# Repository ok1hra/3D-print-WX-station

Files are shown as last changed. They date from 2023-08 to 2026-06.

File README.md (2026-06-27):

# 3D print WX station

Firmware and 3d models

[Wiki page](https://remoteqth.com/w/doku.php?id=3d_print_wx_station)

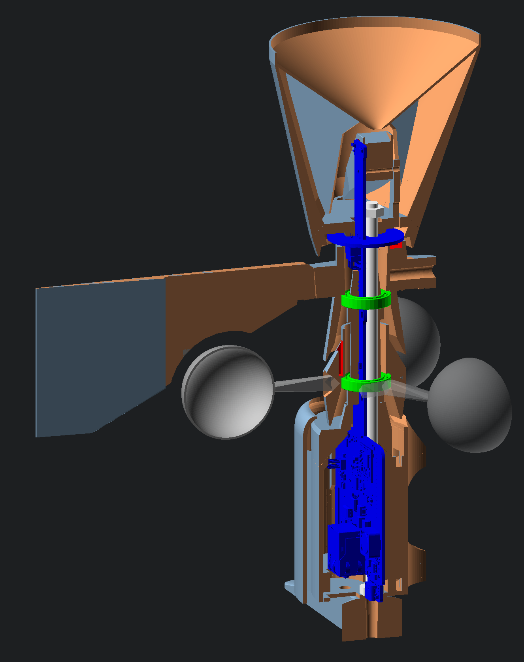
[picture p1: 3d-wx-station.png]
Hardware


## Documentation

- **[Web upload firmware](https://ok1hra.github.io/3D-print-WX-station/)**
- **[Firmware Manual](MANUAL.md)** — network services & ports, web interface,
  serial/telnet console, configuration, building/flashing, and a reference table
  of how often each value is published to MQTT, APRS, windy.com and the dashboard.
- [windy.com setup](WINDY.md) — registering and configuring the windy.com PWS upload.
- [TMEP.cz upload](TMEP.md) — pushing measured values to TMEP.cz (Network tab, per-sensor parameter mapping, NVS config).

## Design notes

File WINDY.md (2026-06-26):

# Sending data to windy.com (PWS)

The WX station can send its measured data to [windy.com](https://www.windy.com)
as a Personal Weather Station (PWS). Communication uses HTTPS to
`stations.windy.com` in a Wunderground-compatible format.

> The feature is enabled in firmware via `#define WINDY` (file `wx.ino`).
> Without an **API key** nothing is sent — uploading is therefore **off by
> default** until you enter the key.

---

## 1. Get an API key

1. Sign in / register at <https://stations.windy.com>.
2. Under **My stations**, *Add a station*:
   - fill in the name, location (lat/lon), altitude and type.
3. After saving, windy generates an **API key** (a long string, up to 123
   characters) and a **Station ID** for the station.
4. Copy the **API key** — you will enter it into the station.

---

## 2. Set the key in the WX station

The key is entered through the configuration menu (telnet or serial console),
just like the other parameters (callsign, coordinates, altitude…).

1. Connect to the station:
   - **telnet** to the station IP (port 23), or
   - **USB serial console** (115200 Bd).
2. Press `?` to list the menu. You will see a new item:

   ```
   K  windy.com API key [empty, upload OFF]
   ```

3. Press `K`.
4. Paste the API key from windy and confirm with **Enter** (`;` on the serial
   console).
5. The station replies, for example:

   ```
   windy API key saved (96 chars)
   ```

   and the menu item changes to `K  windy.com API key [SET, upload ON]`.

The key is stored in EEPROM (addresses 244–367), so it **survives a restart** and
a power loss.

### Disabling uploads / erasing the key
Press `K` and confirm an **empty** input (just Enter). The key is erased and
uploading is turned off:

```
windy upload disabled (key erased)
```

---

## 2b. Public Station ID and the link on the main page

To make a **WINDY** link appear on the station's main web page (port 80) next to
the **APRS** link, also enter the station's public **Station ID**.

- **API key** (step 2) = the secret key used for uploading (~96 characters).
- **Station ID** = the short public identifier in the station's URL, e.g.
  `pws-f06ea43a` (found at <https://stations.windy.com> for the station, i.e. in
  the public URL `https://www.windy.com/station/pws-…`).

To set it:

1. In the menu press `I`.
2. Paste the Station ID (e.g. `pws-f06ea43a`) and confirm with **Enter** (`;` on
   the serial console).
3. The station replies:

   ```
   windy Station ID saved | https://www.windy.com/station/pws-f06ea43a
   ```

The **WINDY** link is shown on the main page **only when both**:
- an API key is set (upload is active), and
- a Station ID is filled in.

Result in the page header:

```
… | APRS | WINDY | Upload FW | …
```

Erase the Station ID by entering an empty value for command `I` (the link then
hides).

---

## 3. Altitude and coordinates

For the data to make sense:

- Set the **altitude** in the menu with command `m` (also used to convert pressure
  to sea level).
- The station coordinates are entered directly on the windy.com website for that
  station.

---

## 4. How often it is sent

Data is sent at the same interval as the other outputs (MQTT, APRS) — the
**"TX repeat time"** in the menu (command `x`), default **5 minutes**.
Windy recommends sending no more often than about once every 5 minutes, so the
default value does not need changing.

---

## 5. What is sent (and in which units)

The firmware converts its internal metric values to the imperial units windy
expects:

| Quantity | windy parameter | unit | firmware conversion |
|---|---|---|---|
| Wind direction | `winddir` | ° | – |
| Wind speed | `windspeedmph`  | mph | m/s ÷ 0.44704 |
| Wind gust | `windgustmph` | mph | m/s ÷ 0.44704 |
| Temperature | `tempf` | °F | °C × 1.8 + 32 |
| Rain (today) | `rainin` | inches  | mm ÷ 25.4 |
| Pressure | `baromin` | inHg | hPa × 0.02953 |
| Dew point | `dewptf` | °F | °C × 1.8 + 32 |
| Humidity | `humidity` | % | – |

---

## 6. Verification / debugging

Enable debugging from the menu with command `*` (debug). The console then shows:

```
[windy] connecting to stations.windy.com ...
[windy] free heap before: 224740
[windy] connected!
[windy] GET /pws/update/XXXX?winddir=...&windspeedmph=... HTTP/1.1
[windy] headers received
[windy RX] ... server response ...
[windy] stop
```

- `connection failed!` → check internet/DNS, the clock (TLS needs a valid time via
  NTP), and that the station has connectivity (Ethernet up, MQTT connected).
- `no API key set, skip upload` → no key is set (see step 2).
- Data appears for the station under **My stations** on windy.com within a few
  minutes.

---

## 7. Memory notes (important)

The feature was originally disabled because of low RAM. The current implementation
solves that:

- **The TLS client (`WiFiClientSecure`) is created locally** inside the upload
  function, so its ~30–40 kB of buffers are **freed** after each upload (it used to
  be global and held memory permanently).
- By default `client.setInsecure()` is used — the server **certificate is not
  verified**, which saves memory. For weather data this is acceptable.
- Free heap is printed before each upload (`free heap before:`), so the trend can
  be watched (it is also published via the MQTT topic `FreeHeap`).

### Optional: certificate verification
If you want full TLS certificate verification (higher RAM demand), uncomment in
`wx.ino`:

```cpp
#define WINDY_VERIFY_CERT
```

This enables verification against the built-in ISRG Root X1 certificate (valid
until 2035).

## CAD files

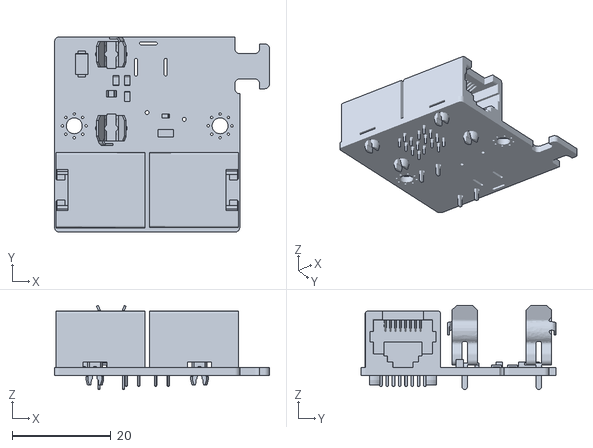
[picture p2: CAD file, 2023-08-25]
3d-print/poe-injector-05.stl
43.5 x 39.5 x 17.0

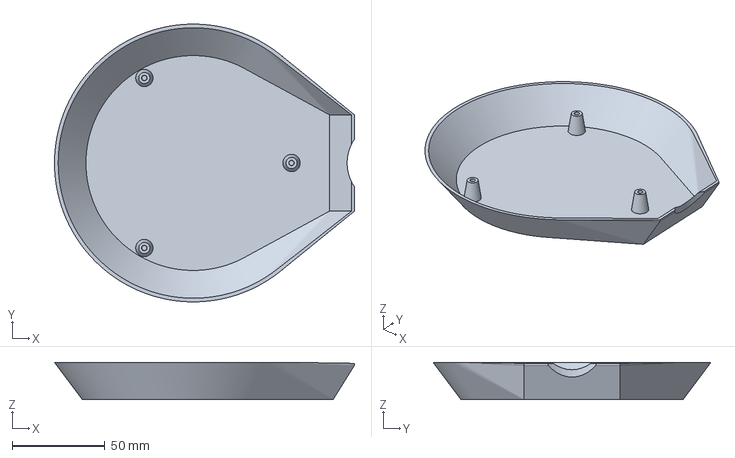
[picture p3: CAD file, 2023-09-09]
3d-print/stl-output-sunshield/1-42mm.3mf
162.0 x 150.0 x 20.0 mm

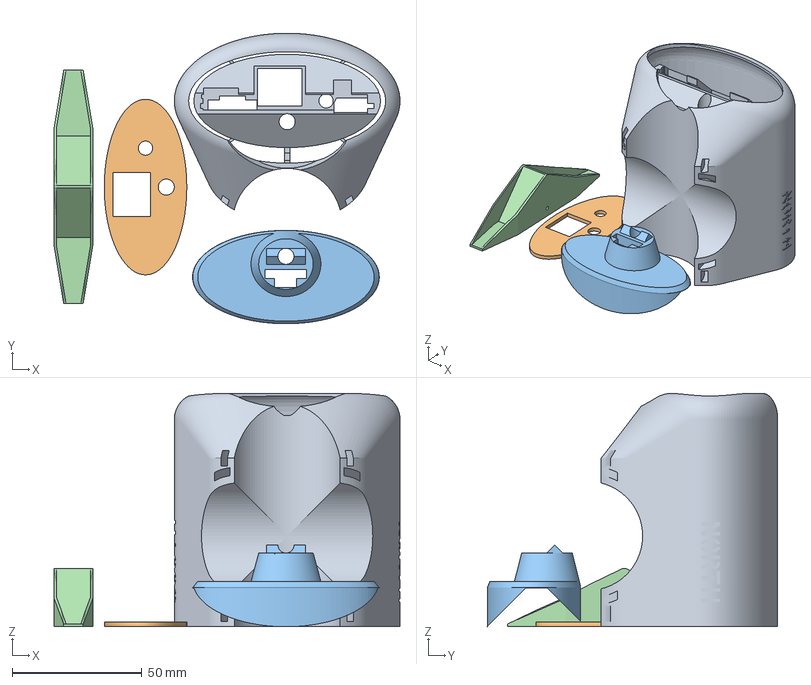
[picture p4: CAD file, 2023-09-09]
3d-print/stl-output/WHITE.3mf
133.4 x 112.0 x 90.0 mm
2.stl
1.stl
3.stl
11.stl

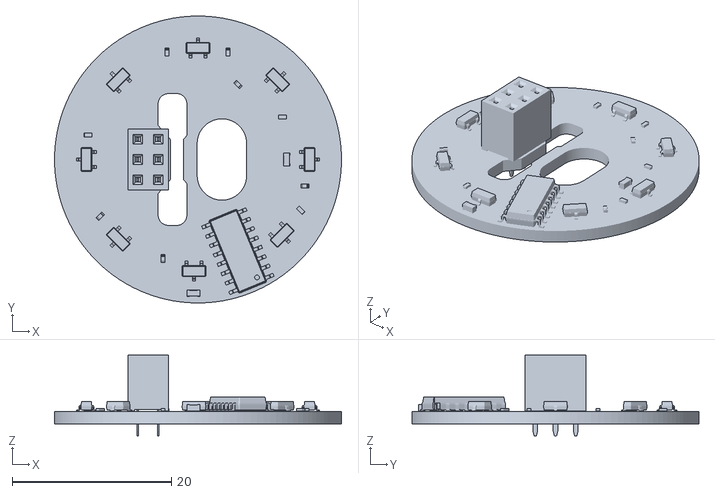
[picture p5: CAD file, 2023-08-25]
3d-print/pcb-wx-06-COIN.stl
36.0 x 36.0 x 10.1

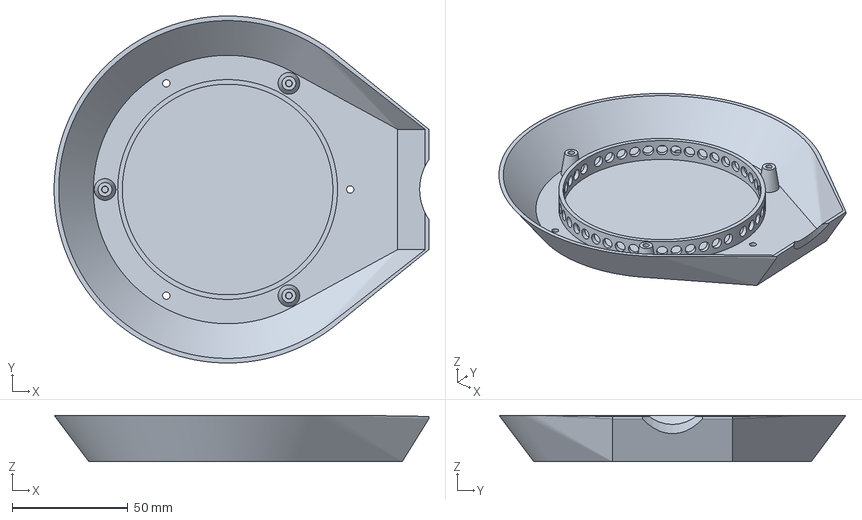
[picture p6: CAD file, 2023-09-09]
3d-print/stl-output-sunshield/2-42mm.3mf
162.0 x 150.0 x 20.0 mm

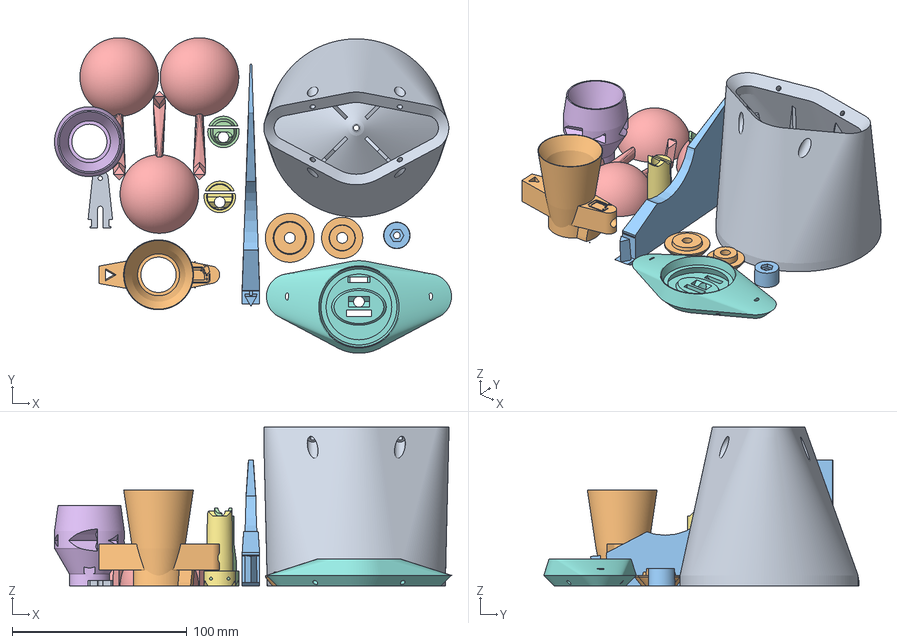
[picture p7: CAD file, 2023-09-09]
3d-print/stl-output/BLACK.3mf
227.4 x 180.7 x 90.9 mm
12.stl
9.stl
8.stl
7.stl
6.stl
5.stl
4.stl
10.stl
13.stl
16.stl
18.stl

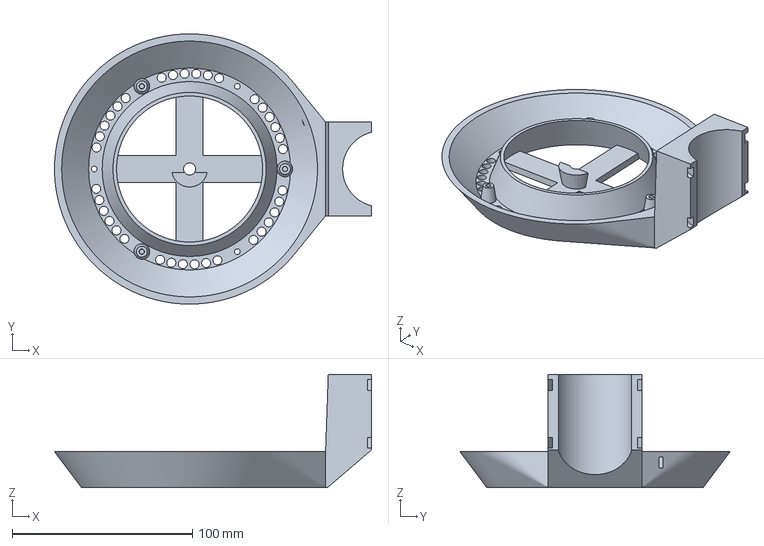
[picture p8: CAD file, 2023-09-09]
3d-print/stl-output-sunshield/3-42mm.3mf
176.0 x 150.0 x 63.0 mm

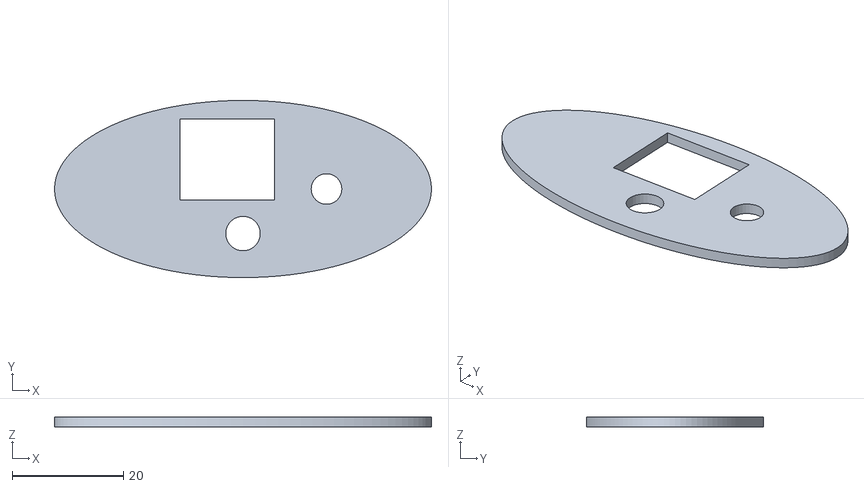
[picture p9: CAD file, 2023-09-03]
3d-print/stl-output/1.stl
67.7 x 31.8 x 1.80

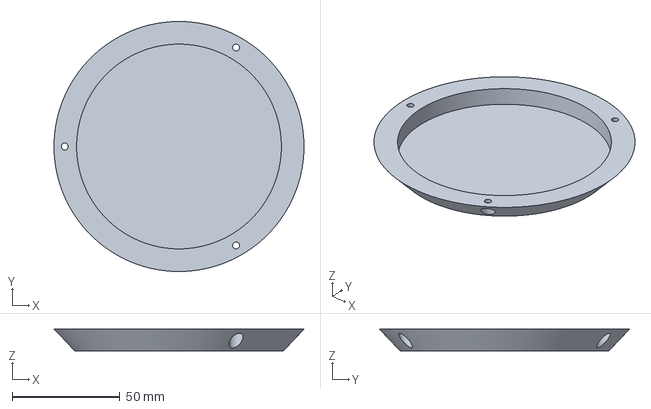
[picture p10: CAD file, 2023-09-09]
3d-print/stl-output-sunshield/5.3mf
116.0 x 116.0 x 10.0 mm

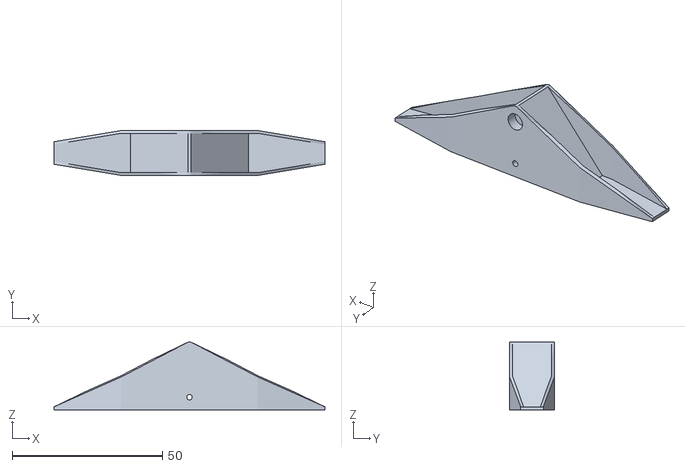
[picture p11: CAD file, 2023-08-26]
3d-print/stl-output/11.stl
90.1 x 15.0 x 22.5

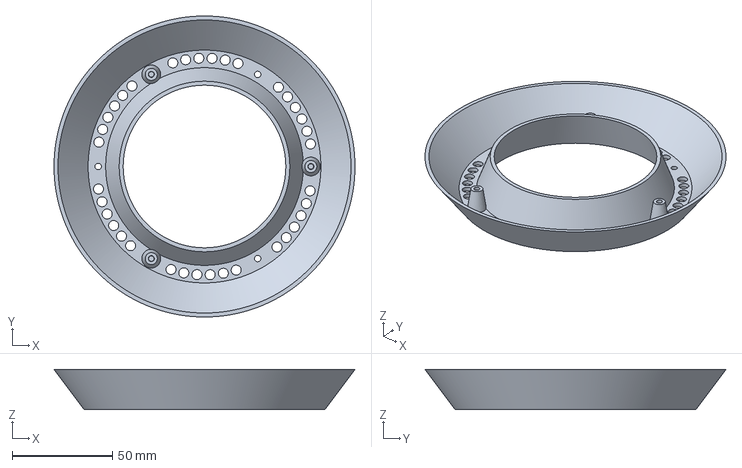
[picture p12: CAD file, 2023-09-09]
3d-print/stl-output-sunshield/4.3mf
150.0 x 150.0 x 20.0 mm

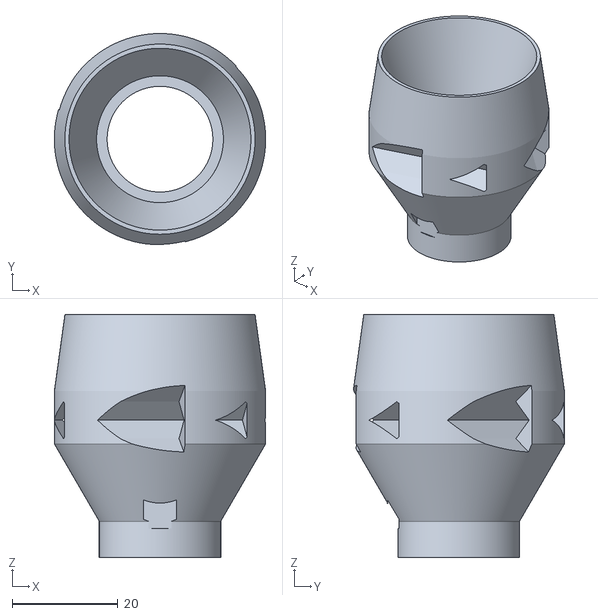
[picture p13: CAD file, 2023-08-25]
3d-print/stl-output/5.stl
40.0 x 39.9 x 46.0

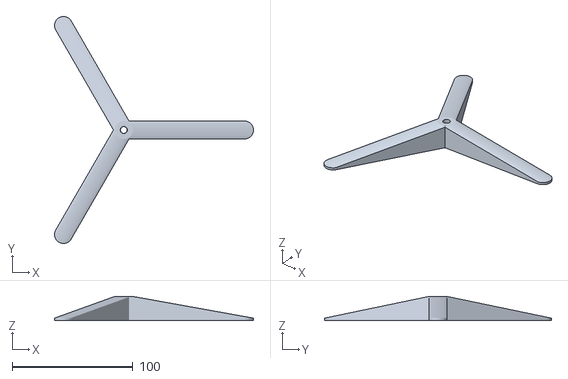
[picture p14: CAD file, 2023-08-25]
3d-print/stl-output/14.stl
165.0 x 188.1 x 20.0

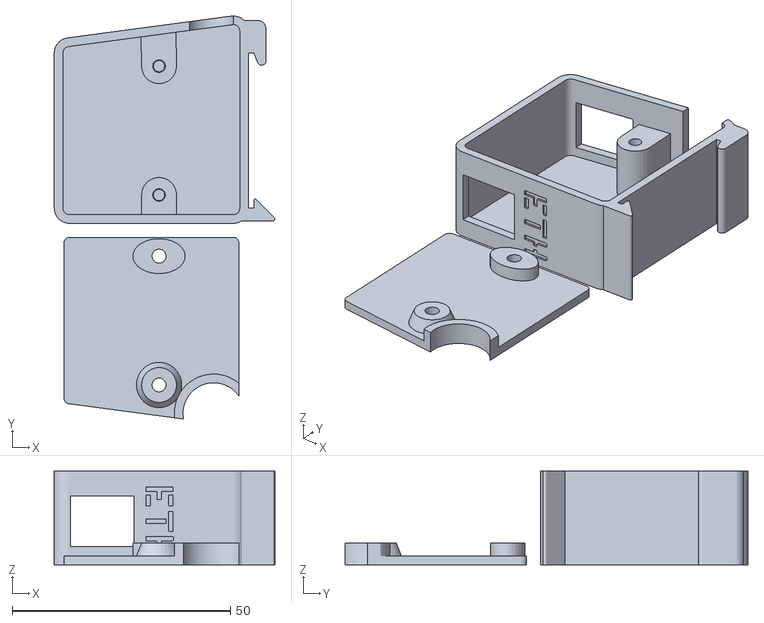
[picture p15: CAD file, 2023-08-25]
3d-print/stl-output/15.stl
50.5 x 92.3 x 21.5

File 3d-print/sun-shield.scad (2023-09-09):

/*-------------------------------------------------------------------
 title: WX station termistor sun shield
 author: OK1HRA 
 license: Creative Commons BY-SA
 URL: http://remoteqth.com/3d-wx-station.php
 revision: 0.1
 format: OpenSCAD
-------------------------------------------------------------------
 HowTo:
 After open change inputs parameters and press F5
 .STL export press F6 and menu /Design/Export as STL...
-------------------------------------------------------------------
 Changelog:
      2023-09 - minor bugfix
      2021-01 - initial relase
------------------------------------------------------------------- */

MOUNTDIA     =    42;    // mounting pipe diameter in mm
Part                     =       0;    // select part 1-5, 0=preview All

//-------------------------------------------------------------------

// don't edit this variables
OutsideDiameter = 150;
InsideDiameter     = OutsideDiameter-30;
VerticalEdge  = 20;
WallThickness = 2;
VerticalDistance = 13;
M3diaFrom = 3.0;
M3diaTo = 2.7;

//-------------------------------------------------------------------



// 4stl
    if(Part==1){
        // top - dependency to mountdia
        translate([0,0,-13*2]) baseTop(OutsideDiameter, InsideDiameter, VerticalEdge, WallThickness, 10, VerticalDistance, MOUNTDIA,0);
    }
    if(Part==2){
        // under top - dependency to mountdia
        translate([0,0,-13]) baseTop(OutsideDiameter, InsideDiameter, VerticalEdge, WallThickness, 10, VerticalDistance, MOUNTDIA,60);
    }
    if(Part==3){
        // moutpoint part - dependency to mountdia
        base(OutsideDiameter, InsideDiameter, VerticalEdge, WallThickness*2, 10, VerticalDistance, MOUNTDIA);
    }
    if(Part==4){
        // bottom sunshield
        translate([0,0,13]) Shield(OutsideDiameter, InsideDiameter, VerticalEdge, WallThickness, 10, VerticalDistance);
    }
    if(Part==5){
        // bottom protect
         translate([0,0,65]) rotate([180,0,0]) bottom(VerticalEdge);
    }
    if(Part==0){
// preview complete
        difference(){
            color([1,1,1]) union(){
                // top
                translate([0,0,-13*2]) baseTop(OutsideDiameter, InsideDiameter, VerticalEdge, WallThickness, 10, VerticalDistance, MOUNTDIA,0);
                // under top
                translate([0,0,-13]) baseTop(OutsideDiameter, InsideDiameter, VerticalEdge, WallThickness, 10, VerticalDistance, MOUNTDIA,60);
                // moutpoint part
                base(OutsideDiameter, InsideDiameter, VerticalEdge, WallThickness*2, 10, VerticalDistance, MOUNTDIA);
#                cylinder(h=50,d=6,center=false,$fn=30);
                // bottom sunshield
                 for(ZZZ = [13 : 13 : 60]){
                    translate([0,0,ZZZ]) Shield(OutsideDiameter, InsideDiameter, VerticalEdge, WallThickness, 10, VerticalDistance);
                }
                // bottom protect
                 translate([0,0,65])  bottom(VerticalEdge);
            }
         translate([-125,0,-100]) cube([250,200,400]);
        }
    }
// not use
// translate([20,0,43-15])  dome(205, 2, MOUNTDIA);


module bottom(VerticalEdge){
    difference(){
    cylinder(h=VerticalEdge-10, d1=116, d2=95+2, $fn=300, center=false);
    translate([0,0,-1])cylinder(h=9, d=95, $fn=300, center=false);
          // M3 hole
             for(R = [-60: 120 : 300]){
                rotate([0,0,R]) translate([120/2-10/2-2,0,-1]) cylinder(h=12, d=3.2, $fn=30, center=false);
                rotate([0,0,R]) translate([120/2-10/2-2,0,+2]) cylinder(h=12, d=6.5, $fn=30, center=false);
             }
    }
 }

module baseTop(DIAb, DIAs, ZZ, WALL, DIAi, SPACE, MOUNTDIA, ROTATE){
    difference(){
        union(){
            difference(){
                // outside
                union(){
                    hull(){
                        cylinder(h=ZZ, d1=DIAs, d2=DIAb, $fn=400, center=false);
//                        translate([DIAb/2,0,ZZ/2]) cube([1,MOUNTDIA+10,ZZ], center=true);
                        hull(){
                            translate([DIAb/2,0,ZZ/2]) cube([1,MOUNTDIA+10,ZZ], center=true);
                            translate([DIAb/2,0,ZZ-1]) cube([MOUNTDIA/3+10,MOUNTDIA+10,1], center=true);
                        }
                    }
                }
                hull(){
                    translate([0,0,WALL]) cylinder(h=ZZ-WALL+0.01, d1=DIAs-WALL*2, d2=DIAb-WALL*2, $fn=250, center=false);
                        hull(){
                            translate([DIAb/2-WALL,0,ZZ/2+WALL]) cube([1,MOUNTDIA+10,ZZ], center=true);
                            translate([DIAb/2-WALL/2,0,ZZ-1+WALL]) cube([MOUNTDIA/3+10,MOUNTDIA+10,1], center=true);
                        }

                }
                // - MOUNTDIA
                translate([DIAb/2+MOUNTDIA/2+10,0,0]) cylinder(h=ZZ+MOUNTDIA*1.5, d=MOUNTDIA+4, $fn=50, center=false);                
            }
            // IN
            if(ROTATE !=0){
                translate([0,0,WALL]) cylinder(h=SPACE-3, d=DIAs-DIAi*2.5, $fn=250, center=false);
            }
        }
        // -IN
        if(ROTATE !=0){
            translate([0,0,WALL]) cylinder(h=SPACE-3+0.01, d=DIAs-DIAi*2.5-2*WALL, $fn=250, center=false);
             for(R = [0 : 8 : 175]){
                rotate([0,0,R]) translate([0,0,7]) rotate([0,90,0]) cylinder(h=DIAs, d=5, center=true, $fn=30);
            }
        }
          // window
//         for(R = [-15 : 30 : 315]){
//            rotate([0,0,R]) translate([DIAs/2-DIAi/2-2,0,-1]) cylinder(h=WALL+2, d=6, $fn=30, center=false);
//         }
          // M3 hole
        if(ROTATE !=0){
             for(R = [-60+ROTATE : 120 : 300+ROTATE]){
                rotate([0,0,R]) translate([DIAs/2-DIAi/2-2,0,-1]) cylinder(h=WALL+2, d=3.2, $fn=30, center=false);
             }
         }
    }
    // spacers
     for(R = [0+ROTATE : 120 : 360+ROTATE]){
        rotate([0,0,R]) translate([DIAs/2-DIAi/2-2,0,0]) 
            difference(){
                cylinder(h=SPACE, d1=DIAi, d2=6, $fn=30, center=false);
                cylinder(h=SPACE+0.1, d=2.7, $fn=30, center=false);
                translate([0,0,SPACE-8.9])cylinder(h=9, d1=M3diaTo, d2=M3diaFrom, $fn=30, center=false);
            }
     }
}



module dome(DIA, WALL, MOUNTDIA){
         difference(){
            sphere(d=DIA, $fn=300); 
            difference(){ 
                sphere(d=DIA-2*WALL, $fn=50); 
                translate([0,0,-DIA*0.73+WALL*2]) cube([DIA+2,DIA+2,DIA], center=true);
            }
            translate([0,0,DIA/2]) cube([DIA*2,DIA+2,DIA], center=true);
            translate([0,0,-DIA*0.73]) cube([DIA+2,DIA+2,DIA], center=true);
//            translate([150/2+MOUNTDIA/3,0,-15]) cube([MOUNTDIA/3+10, MOUNTDIA+10+4, MOUNTDIA], center=true);
        }
 }
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

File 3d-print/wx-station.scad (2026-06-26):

/*-------------------------------------------------------------------
 title: WX station
 author: OK1HRA 
 license: Creative Commons BY-SA
 URL: http://remoteqth.com/3d-wx-station.php
 format: OpenSCAD
-------------------------------------------------------------------
 HowTo:
         After open change inputs parameters and press F5
         .STL export press F6 and menu /Design/Export as STL...
-------------------------------------------------------------------
 Changelog:
        2022-09 - massive redesign to PCB rev 0.7
        2020-04 - add door and binder mount for external termistor wire
        2020-04 - initial relase
-------------------------------------------------------------------
        Legend
        BLUE     - PCB electronic
        RED      - neodym magnets
        GREEN    - bearings
//------------------------------------------------------------------- */
        Part             = 2;    // select part 1-18, -x=all, 17=variant of inner
                                   // ./render.sh bash script generate all parts
        BearingInTuning  = +20;    // +- smooth tuning bearing inner diameter in um
        MountDia         =  42;     //30.2/cos(45);    // mm tube size for mounting
        MountDiaFn       = 120;    // mount tube polygon, 4 for square
        CUT              =   0;    // 0/1 hlaf cut view enable
        Strong           =   0;    // 1 enable strongest (part 6 only)
//-------------------------------------------------------------------

// PARAMETERS
MagnetX=2.2;
MagnetY=6.2;
MagnetZ=12;

RODshift=3.0;

PCBshift=2.7;
PCBwidth=14;

tloustka = 2;
height = 70;
space = 0.2;
M3 = 3.2;
diameter = 70;

difference(){
    Build2(Part);
    // -cut
    if (CUT>0&&Part<0) {
//    rotate([0,0,-90])
        translate([-70-5+5,0,100]) cube([140, 200, 400], center=true);
    }
}


module Build2(Part){
    // variant of inner
    if(Part==17){
        for(i= [-30 : 10 : 30]){
            translate([i*2,25,0]) In(40, 0.4, 1.6, i);    // ZZ, MINUS    // 10
            translate([i*2,0,0]) In(40, 0.4, 0, i);    // ZZ, MINUS    // 07
        }
    }    

    // Bearing press
    if(Part==16){
//        color([0,1,0])  translate([0, 0, 8.5+1]) rotate([0,90,0]) import("61802.stl", convexity = 5);
        difference(){
            union(){
                translate([0,0,6]) cylinder(h=4, d1=15, d2=14.5, center=false, $fn=200);
                translate([0,0,5]) cylinder(h=1.01, d=23.6, center=false, $fn=160);
                translate([0,0,0]) cylinder(h=5.01, d2=23.6, d1=15, center=false, $fn=160);
            }
            translate([0,0,-1]) cylinder(h=30, d=6.2, center=false, $fn=60);
            translate([0,0,-1]) cylinder(h=4, r=10/sin(60)/2, center=false, $fn=6);

        }

        difference(){
            union(){
                translate([30,0,6]) cylinder(h=2, d1=19, d2=18, center=false, $fn=200);
                translate([30,0,5]) cylinder(h=1.01, d=28, center=false, $fn=160);
                translate([30,0,0]) cylinder(h=5.01, d2=28, d1=20, center=false, $fn=160);
            }
            translate([30,0,-1]) cylinder(h=30, d=6.2, center=false, $fn=60);
        }
    }    

     // POE     // 15
    if(Part==15){
        translate([0,-8, 17.5]) rotate([180,0,0]) 
        POEboxTOP();
//        color([0,0,1]) rotate([180,0,90]) translate([4,1,-14.5]) import("poe-injector-05.stl", convexity = 5);
        POEbox();
    }

    // Stand        // 14
    if(Part==14 || Part<0){
        translate([0,-RODshift,-25]) Stand(20);
    }

    // rain cylinder    // 13
    if(Part==13){
        translate([0,0,256]) rotate([180,0,0]) RainCylinder();
    }else if(Part<0){
        RainCylinder();
    }

module RainCylinder(){
    difference(){
        hull(){
            translate([0,0-6, 256.6]) cylinder(h=1+5, d=100+2, center=false, $fn=200);
            translate([0,0,171.65]) cylinder(h=6, d=47+6, center=false, $fn=200);
            translate([40,-6, 171.65]) cylinder(h=6, d=20+6, center=false, $fn=200);
            translate([-40,-6, 171.65]) cylinder(h=6, d=20+6, center=false, $fn=200);
        }
        difference(){
            hull(){
                translate([0,0-6, 257.6]) cylinder(h=1+5, d=100, center=false, $fn=200);
                translate([0,0,177.5]) cylinder(h=8, d1=47-6, d2=41+7, center=false, $fn=200);
                translate([40,-6, 177.5]) cylinder(h=8, d=20-6, d2=14+7, center=false, $fn=200);
                translate([-40,-6, 177.5]) cylinder(h=8, d=20-6, d2=14+7, center=false, $fn=200);
            }
            CrosSupport();
        }
        rotate([180,0,0]) hull(){
                    translate([0,0,-177.6]) cylinder(h=6, d1=47.1-6, d2=47.1+6, center=false, $fn=100);
                    translate([40,6,-177.6]) cylinder(h=6, d1=20.1-6, d2=20.1+6, center=false, $fn=100);
                    translate([-40,6,-177.6]) cylinder(h=6, d1=20.1-6, d2=20.1+6, center=false, $fn=100);
        }
        translate([25,-20.5,178]) rotate([45,0,0]) M3(10);      //     rotate([180,0,0]) cylinder(h=LENGTH, d=3.2, $fn=30, center=false);
        translate([25,14.5,178]) rotate([-45,0,0]) M3(10);
        translate([-25,-20.5,178]) rotate([45,0,0]) M3(10);
        translate([-25,14.5,178]) rotate([-45,0,0]) M3(10);
    }
    // top for water
    difference(){
        hull(){
            translate([0,0-6, 256.6]) cylinder(h=1, d=100+2, center=false, $fn=200);
            translate([0,0-6, 221.1+1]) cylinder(h=1, d=5+4, center=false, $fn=200);
            translate([0,0-6, 221.1]) cylinder(h=1, d=4.5, center=false, $fn=200);
        }
        hull(){
            translate([0,0-6, 257.6]) cylinder(h=1, d=100, center=false, $fn=200);
            translate([0,0-6, 221]) cylinder(h=1, d=3, center=false, $fn=200);
        }
    }
}

module CrosSupport(){
        difference(){
            union(){
                translate([0,-6,177.6+40]) rotate([0,0,45]) cube([100,2,80], center=true);
                translate([0,-6,177.6+40]) rotate([0,0,-45]) cube([100,2,80], center=true);
            }
            hull(){
                translate([0,0-6, 256.7]) cylinder(h=1, d=100+2, center=false, $fn=200);
                translate([0,0-6, 221.1]) cylinder(h=1, d=5, center=false, $fn=200);
            }
            difference(){
                translate([0,-6,177.6+40]) cube([110,110,82], center=true);
                hull(){
                    translate([0,0-6, 256.6]) cylinder(h=1, d=100+2, center=false, $fn=200);
                    translate([0,0,171.65]) cylinder(h=6, d=47+6, center=false, $fn=200);
                    translate([40,-6, 171.65]) cylinder(h=6, d=20+6, center=false, $fn=200);
                    translate([-40,-6, 171.65]) cylinder(h=6, d=20+6, center=false, $fn=200);
                }
            }
            translate([0,-6,177+40]) cylinder(h=10, d1=36, d2=10, center=false, $fn=200);
            translate([0,-6,177]) cylinder(h=40.01, d1=50, d2=36, center=false, $fn=200);
        }
}

    // formatting bearing// 18
    if(Part==18){
        difference(){
            cylinder(h=10, d1=15.2, d2=14.8, center=false, $fn=300);
            translate([0,0,-1]) cylinder(h=12, d=3.8, center=false, $fn=30);
            translate([0,0,8]) cylinder(h=4, r=7/sin(60)/2, center=false, $fn=6);
        }
    }

    // water measure support    // 12
    if(Part==12){
        rotate([90,0,0]) supp4swing(3, 0, 23.5);
    }else if(Part<0){
        translate([0,-15.5,170.6+7]) supp4swing(3, 0, 23.5);     // hh, EXPAND, ZZ
    }
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

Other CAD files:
3d-print/stl-output/3.stl
3d-print/stl-output/9.stl
3d-print/stl-output/16.stl
3d-print/stl-output/7.stl
3d-print/61802.stl
3d-print/stl-output-sunshield/1-42mm.stl
3d-print/stl-output-sunshield/2-42mm.stl
3d-print/stl-output-sunshield/3-42mm.stl
3d-print/stl-output-sunshield/4.stl
3d-print/stl-output-sunshield/5.stl
3d-print/stl-output/10.stl
3d-print/stl-output/12.stl
3d-print/stl-output/13.stl
3d-print/stl-output/4.stl
3d-print/stl-output/8.stl
3d-print/stl-output/TRANSPARENT.3mf

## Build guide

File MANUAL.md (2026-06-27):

# WX Station — Firmware Manual

Firmware for the 3D-printed weather station, running on an **Olimex ESP32-POE** board.
Firmware revision string: see `REV` in `wx.ino` (date-based, e.g. `20260626`).

- Wiki: https://remoteqth.com/w/doku.php?id=3d_print_wx_station
- Source: [`wx.ino`](wx.ino) · Web UI: [`data/`](data/) (SPIFFS)

---

## 1. Overview

The station samples wind (direction + speed), rain, temperature, humidity and
barometric pressure, and distributes the data over five channels:

- **MQTT** — telemetry to a broker (default public `54.38.157.134:1883`).
- **APRS-IS** — weather frame to the APRS network (`czech.aprs2.net:14580`).
- **windy.com** — PWS upload (HTTPS).
- **TrxNet** — P2P binary telemetry over the local LAN (UDP, no broker/internet) — see §4.
- **Web dashboard** — local responsive page plus a setup/diagnostics UI.

Sensors supported (compile-time `#define`, auto-detected at boot): HTU21D
(humidity + temperature), BMP280 (pressure + temperature), DS18B20 (external
temperature, used as master when present), optional RF69 radio sensor.

### Wind measurement architecture (dual-core)

Wind-speed pulses from the anemometer are counted in an **IRAM-safe interrupt
(ISR)** that does all min / max / average accumulation itself, under a spinlock.
Because the ISR runs on every pulse regardless of what `loop()` is doing, **no
gust is lost** — not while the main loop is busy serving the web, MQTT or the
multi-second windy.com TLS upload, and not during EEPROM writes (the interrupt is
no longer detached for those).

A dedicated **`WindTask` pinned to core 0** (the Ethernet/lwIP core, which has
spare capacity because there is no Wi-Fi driver task) refreshes the live wind
cache and pushes it to the dashboard. It is non-critical to measurement: the gust
accumulation lives in the ISR, so even if the task stalled, no data would be lost.
This makes high-wind capture and real-time web display fully independent.

---

## 2. Network services & ports

| Service | Port | Notes |
|---|---|---|
| Web dashboard + setup | 80 | `/` dashboard, `/setup` config, `/wall` MQTT wall |
| OTA update (firmware + filesystem) | 82 | `http://<ip>:82/update` |
| Live-wind SSE stream | 82 | `/events` — Server-Sent Events, CORS-enabled (dashboard needle) |
| Telnet console | 23 | key-authenticated (key printed on serial at boot) |
| MQTT | broker-defined | default broker `54.38.157.134:1883` |
| TrxNet | UDP 5683 (configurable) | P2P discovery + telemetry, local LAN broadcast — see §4 |

mDNS is advertised, so the station is also reachable by hostname `WX-<CALLSIGN>`.

All web services (dashboard, setup, OTA, SSE) are served by the station itself, so
the UI works on an **isolated LAN without internet** — see §3.

---

## 3. Web interface

### Dashboard `/`
Public responsive meteo page, served from SPIFFS. Layout: large temperature, a
sensor grid (humidity, pressure, rain, dew point, **Wind max 5 min**, **wind
direction**) and a **wind-speed gauge** with a coloured needle.

Live wind is **pushed** from the firmware over **Server-Sent Events** (`/events`
on port 82) by the core-0 `WindTask`: a new pulse triggers a push (rate-limited to
≤10 Hz) plus a 1 s keep-alive, so the gauge needle and direction track gusts
within ~50–100 ms without polling. If the SSE stream is unavailable the page
transparently falls back to polling `/api/wind` every 2 s. The slower sensors
(temperature, humidity, pressure, rain) refresh from `/api/live` every 30 s.

- **Gauge** — 0–25 m/s, scale labels every 5 m/s, three colour zones (green ≤8,
  orange ≤14, red >14 m/s). The needle (and its colour) follow the instantaneous
  speed. Above 25 m/s the needle **pins at full scale** but the numeric read-out
  still shows the **true value** (e.g. 28.0 m/s); the same is true for *Wind max
  5 min*.
- **Wind max 5 min** — a true rolling maximum over the trailing **exactly 5.0 min**
  (1-second resolution), computed independently of the publish cycle. It is
  therefore **decoupled** from the `WindSpeedMaxPeriod-mps` value sent to MQTT /
  APRS / windy.com (which resets every publish cycle).

#### Offline / island operation
The dashboard is fully **local** and works on a LAN with **no internet**: the page,
`/api/live`, `/api/wind` and the `/events` push all come from the station. The
measurement path is **decoupled from MQTT** — the 5-min measurement cycle runs on
the ETH link alone, so the **DS18B20** external temperature (every 5 min), the
today's-rain EEPROM persistence and the period-max reset all keep working without a
broker. The software watchdog reboots only on **ETH** loss, never on MQTT loss, so
an island station stays up. Only genuinely internet-dependent extras degrade:

- **NTP clock** — without internet `configTime`/NTP can't sync, so timestamps
  (UTC, *Wind max* time) show `n/a`; all measured values still update.
- **External links** (aprs.fi, windy.com) and the **uploads** (MQTT / APRS /
  windy) need connectivity; their absence does not affect the live dashboard.

The station needs a valid IP on the LAN (local DHCP or a static address).

### Setup `/setup`
Tabbed configuration and diagnostics page. Optionally protected by HTTP Basic
auth (see §6). Tabs:

- **Station** — altitude, callsign/name (`CALLSIGN-ssid`), rain mm/pulse, wind
  direction offset, temperature calibration.
- **Network** — MQTT broker IP/port, APRS (enable, password, coordinates),
  windy.com (API key, station ID). APRS sends as the **`CALLSIGN-ssid`** value
  from the Station tab.
- **System** — web security (password), diagnostics (firmware, uptime, MAC, IP,
  NTP, heap, MQTT, SPIFFS).
- **Status** — full live sensor dump including **raw / debug values** (mirrors the
  telnet status block): wind-direction register, RPM pulse periods, RainPin ADC,
  raw vs calibrated temperatures, raw barometric pressure. Polls `/api/status`
  every 5 s while the tab is open.
- **Debug** — serial debug level + recent log lines.

### HTTP API
| Endpoint | Auth | Purpose |
|---|---|---|
| `GET /api/live` | public | cached meteo JSON (dashboard, 30 s) |
| `GET /api/wind` | public | small wind JSON: live dir + speed + rolling 5-min max (fast-poll fallback) |
| `GET /events` (port 82) | public | SSE live-wind stream pushed by `WindTask` (dir, speed, rolling max) |
| `GET /api/status` | gated | full sensor + raw debug dump (Status tab) |
| `GET /api/config` | gated | settings + diagnostics (secrets masked) |
| `POST /api/config` | gated | save settings |
| `GET /api/debug` | gated | debug level + log ring buffer |
| `GET /api/wallcfg` | public | broker WS URI + topic for `/wall` |

---

## 4. Data publishing — intervals

All channels are driven by a single **measurement cycle** (`wx.ino`, default
**300 000 ms = 5 min**, configurable via the telnet/serial `x` command). The cycle
fires on the **ETH link alone** — it measures (incl. DS18B20), persists today's
rain and resets the period accumulators **regardless of MQTT**. The network uploads
(MQTT, APRS, windy.com) run within the same cycle **only when MQTT is connected**
(used as an "internet is up" proxy), so an offline station still measures and
refreshes everything locally.

| Channel | Interval | Trigger | Payload |
|---|---|---|---|
| **MQTT** | 5 min (configurable `x`) | measurement cycle, if MQTT connected | all meteo values + FreeHeap |
| **MQTT on-demand** | immediate | message to `CALLSIGN/WX/get` (any payload) | meteo values (`MqttPubValue()`) — not APRS/windy |
| **MQTT RF sensor** | on packet (poll ~2 s) | RF69 data received | RF temperature / humidity / battery |
| **MQTT ip/mac** | once per (re)connect | broker connect | IP + MAC (retained) |
| **APRS** | 5 min | measurement cycle, if MQTT connected | one WX frame |
| **windy.com** | 5 min | measurement cycle, if MQTT connected | PWS upload (only if API key set) |
| **TrxNet** | 5 min | measurement cycle (ETH only, **not** gated on MQTT) | 7 binary topics to all peers (see below) |
| **TrxNet greet** | on peer join | new peer discovered | full 7-topic snapshot to that peer (reliable) |
| **DS18B20 / rain persist / period reset** | 5 min | measurement cycle (ETH only) | runs offline too — independent of MQTT |
| **Dashboard live wind** | push via SSE `/events`: on-pulse ≤10 Hz + 1 s keep-alive | core-0 `WindTask` | instantaneous speed, direction, rolling 5-min max |
| **Dashboard `/api/live`** | cache 30 s, browser poll 30 s | `GetValue(false)` (fast sensors, no DS18B20) | temperature, humidity, pressure, rain (+ wind snapshot) |
| **Setup → Status `/api/status`** | 5 s (tab open) | live read | all values incl. raw / debug |

**Notes**

- APRS and windy.com upload **only** in the 5-min cycle; `/get` republishes MQTT
  only, it does not trigger APRS/windy.
- Dashboard **wind** (speed, direction, rolling max) is real-time via SSE push;
  the other sensors have ~30 s latency (fast cache). The **Status** tab is a 5 s
  full live view.
- `WindSpeedMaxPeriod-mps` (MQTT/APRS/windy) is the max of the **current publish
  period** (resets every cycle); the dashboard *Wind max 5 min* is a separate
  rolling 5-min value — the two will usually differ.
- The cycle runs on `eth_connected`; only the MQTT/APRS/windy uploads are gated on
  `mqttClient.connected()`. With no broker the station still measures, refreshes
  DS18B20, persists rain and resets the period — only the uploads pause (see §3,
  offline operation).

### MQTT topics (base `CALLSIGN/WX/...`, published every cycle)
`utc`, `WindDir-azimuth`, `RainCount`, `RainToday-mm`, `WindSpeedAvg-mps`,
`WindSpeedMaxPeriod-mps`, `WindSpeedMaxPeriod-utc`, `Pressure-hPa-BMP280`,
`Temperature-Celsius-BMP280`, `HumidityRel-Percent-HTU21D`,
`DewPoint-Celsius-HTU21D`, `Temperature-Celsius-DS18B20`, `Pressure-hPa`,
`HumidityRel-Percent`, `DewPoint-Celsius`, `Temperature-Celsius` (published last
— acts as the e-ink update trigger), `FreeHeap`.

Subscribed: `CALLSIGN/WX/get` (any payload → immediate re-publish of meteo values).

### TrxNet (local-LAN P2P telemetry)

[TrxNet](https://github.com/ok1hra/TrxNet) is a broker-less peer-to-peer protocol
(UDP discovery + minimal CoAP) for the remoteQTH device family. The station joins
the LAN as **`WX.<id>`** and publishes binary telemetry directly to every peer
(e.g. [TrxNet Monitor](https://github.com/ok1hra/TrxNet/blob/main/MONITOR.md),
NodeRed) — **no broker and no internet required**, so it works on an isolated LAN.

- **Enable / identity:** set **Network ID** in `/setup` → Network (or the field
  writes EEPROM byte 1). `0` = disabled (the station does not join). Non-zero `N`
  → device name `WX.<N hex>` (e.g. `1` → `WX.01`, `255` → `WX.ff`). Change reboots.
- **UDP port:** default **5683**, configurable in `/setup` → Network (EEPROM 32-33).
  All TrxNet devices that should see each other must share the same port; different
  ports segregate independent networks on one LAN. Change reboots.
- **Cadence:** all 7 topics every 5 min (measurement cycle, `TRX_NON` best-effort,
  runs even with no MQTT/internet). A newly discovered peer additionally gets an
  immediate full snapshot (`TRX_CON`, reliable) so it need not wait for the cycle.
- **Discovery** uses LAN broadcast — all devices must be on the same broadcast
  domain (no routing across subnets). Wired ETH is unaffected by Wi-Fi AP isolation.

**Topics** — raw **little-endian scaled integers** (all `uint16_t` except `/temp`
which is `int16_t` for sub-zero):

| Topic | Type | Encoding | Source | Example wire value |
|---|---|---|---|---|
| `/temp` | `int16_t` | °C × 100 | `TemperatureCelsius` | 21.35 °C → `2135` |
| `/hum` | `uint16_t` | % × 100 | `HumidityRelPercent` | 67.50 % → `6750` |
| `/press` | `uint16_t` | hPa × 10 | `PressureHPA` | 1013.2 hPa → `10132` |
| `/rain` | `uint16_t` | mm × 100 (daily total) | `RainTodayMM` | 3.80 mm → `380` |
| `/winddir` | `uint16_t` | degrees 0–359 | `WindDir` | 180° → `180` |
| `/windavg` | `uint16_t` | m/s × 100 | `WindSpeedAvgMPS` | 4.20 m/s → `420` |
| `/windmax` | `uint16_t` | m/s × 100 (period max) | `WindSpeedMaxPeriodMPS` | 9.80 m/s → `980` |

Publish-only — the station subscribes to nothing on TrxNet. Compile-time guard
`#define TRXNET`; library buffer `TRXNET_MAX_PENDING` is raised to 9 in `TrxNet.h`
to fit the 7-topic greet snapshot.

---

## 5. Serial / Telnet console

A single-character menu is available on the USB serial port and over telnet
(telnet additionally requires the access key printed at boot). Press `?` to list
commands. Key commands:

| Key | Action |
|---|---|
| `?` | refresh status / list commands |
| `m` | set altitude (sea-level pressure conversion) |
| `L` | set callsign / location name (`CALLSIGN-ssid`) |
| `R` | set rain mm per pulse |
| `S` | set wind-direction offset |
| `C` | set temperature calibration |
| `x` | set TX repeat time (publish-cycle minutes) |
| `+` | set MQTT broker IP/port (restarts) |
| `A` | toggle APRS, `p` password, `c` coordinates |
| `K` | set windy.com API key · `I` set windy.com station ID |
| `P` | clear web password / disable auth (**recovery**, see §6) |
| `e` | dump EEPROM · `E` erase whole EEPROM (serial only) |
| `W` | erase wind-speed max memory |
| `@` | restart device · `*` toggle serial debug |
| `q` / `Q` | close telnet / logout + forget verified IP |

---

## 6. Web authentication & recovery

The `/setup` page and its write APIs are protected by HTTP Basic auth **only when
a web password is set** (System tab → *Web password*). User is fixed (`admin`).

Because `/setup` is locked behind that password, **disabling auth / recovering a
lost password is not done from the web** — it lives in the out-of-band console:

> Press **`P`** in the serial or telnet menu → confirm → the password is cleared,
> auth is disabled, and the device restarts.

Setting/changing the password is done from the web (when authenticated); clearing
it is console-only.

---

## 7. Building & flashing

Target board: **Olimex ESP32-POE**, ESP32 Arduino core 2.0.14.

```sh
# from the sketch directory
arduino-cli compile --fqbn esp32:esp32:esp32-poe .
```

- Firmware baseline footprint: ~93 % flash, ~18 % static RAM.
- The web UI lives in SPIFFS (`data/`). Changes to `data/*.html` require a
  **filesystem (SPIFFS) upload** — re-flashing only the firmware `.bin` does not
  update the web pages. Use the OTA page (`:82/update`, filesystem image) or the
  filesystem-upload tooling.

## 8. Releasing firmware & the download page

Compiled binaries are published to GitHub Pages at
<https://ok1hra.github.io/3D-print-WX-station/>, which offers both EasyOTA
`.bin` downloads and a browser-based USB recovery installer (esp-web-tools).
The OTA page (`:82/update`) reads that site's `manifest.json` and shows whether a
newer firmware is available.

**One-time setup:** in the GitHub repo, Settings → Pages → Source "Deploy from a
branch" → Branch `gh-pages`, folder `/(root)`. The `gh-pages` branch is created
automatically by the publish script on its first run.

**Release a new version:**

1. Increase `REV` in `wx.ino`.
2. Arduino IDE 1.8.19: Sketch → Export compiled Binary (board ESP32-POE; the
   sketch-local `partitions.csv` is applied automatically).
3. Build all images and publish to GitHub Pages:

   ```sh
   ./tools/all.sh --publish
   ```

4. `git commit` with the release number as the message, then `git push`.

Only the latest release is kept on `gh-pages` (older versioned `wx-*.bin`
files are replaced on each publish).

**Partial update (without a release):**

1. Arduino IDE: Sketch → Export compiled Binary.
2. Build the SPIFFS image: `tools/build_spiffs_image.sh`.
3. Upload `wx.ino.esp32-poe.bin` and `build/spiffs.bin` via EasyOTA
   (`:82/update`, firmware first, then filesystem).
4. `git commit` and push.

The `tools/` scripts:

| Script | Purpose |
| --- | --- |
| `build_spiffs_image.sh` | pack `data/` into `build/spiffs.bin` (mkspiffs) |
| `build_recovery_package.sh` | assemble `build/recovery-web/` (versioned `.bin`, merged image, `manifest.json`, `index.html`) |
| `publish_recovery_to_gh_pages.sh` | push `build/recovery-web/` to the `gh-pages` branch |
| `all.sh` | run the SPIFFS + recovery build, `--publish` also pushes |

See [`WINDY.md`](WINDY.md) for windy.com setup details.

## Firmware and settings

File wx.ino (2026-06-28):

/*
3D printed WX station
----------------------
https://remoteqth.com/w/doku.php?id=3d_print_wx_station
TNX OK1IAK for code help

 ___               _        ___ _____ _  _
| _ \___ _ __  ___| |_ ___ / _ \_   _| || |  __ ___ _ __
|   / -_) '  \/ _ \  _/ -_) (_) || | | __ |_/ _/ _ \ '  \
|_|_\___|_|_|_\___/\__\___|\__\_\|_| |_||_(_)__\___/_|_|_|


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

Release new firmware version:
1. Increase REV value in this .ino
2. Arduino IDE 1.8.19 menu: Sketch/Export compiled Binary
   (HARDWARE ESP32-POE; the sketch-local partitions.csv is applied automatically)
3. generate all .bin and publish to GitHub Pages: $ ./tools/all.sh --publish
4. git commit with the Release number as comment and push

Partial update (without a release):
1. Arduino IDE 1.8.19 menu: Sketch/Export compiled Binary (HARDWARE ESP32-POE)
2. build SPIFFS image: $ tools/build_spiffs_image.sh
3. upload firmware.bin and build/spiffs.bin via EasyOTA at http://[ip]:82/update
4. git commit and push

Firmware download page: https://ok1hra.github.io/3D-print-WX-station/
One-time setup: GitHub repo Settings -> Pages -> Branch: gh-pages, folder /(root)


Send test packet
  echo -n -e '\x00ms:bro;' | nc -u -w1 192.168.1.23 88 | hexdump -C
Remote USB access
  screen /dev/ttyUSB0 115200


mosquitto_sub -h 54.38.157.134 -p 1883 -t "OK1HRA-8/WX/FreeHeap"



HARDWARE ESP32-POE

Changelog:
20260627 - TMEP.cz upload (Network tab, per-sensor parameter mapping, NVS config) + TMEP link on main web page
20260626 - windy.com Station ID ('I' menu cmd, EEPROM 373-404) + WINDY link on main web page next to APRS
20260626 - finish windy.com upload (API key in EEPROM 244-367 + 'K' menu cmd, fix units, local TLS client + setInsecure to save heap)
20260626 - AI bugfix
20231012 - mDNS support
20230917 - windy.com (not work, probably low memory)
20230916 - fix key login, http temperature
20230825 - add dew point, fix shift register, fix MQTT topic
20230815 - recalibrate rain
20221104 - calibrate rain
20220910 - HW rev5, DS18B20 autodetect,
20220429 - add html preview page on port 88
20220307 - add wind direction shift settings for non North orientation, update for new lib
20210513 - add enable support, RF module support by https://github.com/jarodan
20210407 - disable local CLI
20210322 - get actual data on request, via MQTT topic /get (any message)
20210321 - used inaccurate internal temperature sensor, if external DS18B20 disable
20210316 - web firmware upload
20210225 - eeprom bugfix
20210131 - add to menu erase windspeed max memory, fix max speed bug, disable internal temperature sensor
20210123 - calculate pressure with altitude TNX OK1IRG, add altitude settings in CLI
20210122 - bugfix DS18B20 eeprom set
20210116 - WDT bug fix, command listing after telnet login
20201211 - external sensor enable from CLI
20200815 - js url fix
20200814 - add WatchdogTimer for reset
20200620 - addd frenetic mode, calibrate rain sensor
20200509 - first function for calibrate wind sensor
20200424 - add support for external 1-wire temperature ensor (DS18B20)

ToDo
- "Minimal SPIFFS (Large APPS with OTA)" dá 1,9 MB na app a OTA zůstává funkční.
  Tvoje webové stránky v data/ mají jen 60 KB → do 190 KB SPIFFS se v pohodě vejdou.
  Kompilace: přidat --board-options PartitionScheme=min_spiffs
  V Arduino IDE: Tools → Partition Scheme → Minimal SPIFFS (Large APPS with OTA).
V pripade pouziti detekovat v ota starsi verze FW a neumoznit je nahrat


- web setup
- web selfcheck
- Windy
  https://community.windy.com/topic/8168/report-your-weather-station-data-to-windy
  https://github.com/zpukr/esp8266-WindStation/blob/master/esp8266-WindStation.ino
- Sunset https://github.com/buelowp/sunset/blob/master/examples/esp/example.ino
- telnet inactivity to close
- clear code
- https://github.com/Sensirion/arduino-sht
APRS-lora
https://how2electronics.com/esp32-lora-thingspeak-gateway-sensor-node/
https://learn.adafruit.com/adafruit-rfm69hcw-and-rfm96-rfm95-rfm98-lora-packet-padio-breakouts/rfm9x-test
https://github.com/lora-aprs/LoRa_APRS_Tracker/blob/master/src/configuration.cpp#L73
https://github.com/josefmtd/lora-aprs
https://on5vl.org/lora-aprs-le-guide-pratique/


Použití knihovny WiFi ve verzi 2.0.0 v adresáři: /home/dan/Arduino/hardware/espressif/esp32/libraries/WiFi
Použití knihovny EEPROM ve verzi 2.0.0 v adresáři: /home/dan/Arduino/hardware/espressif/esp32/libraries/EEPROM
Použití knihovny Ethernet ve verzi 2.0.0 v adresáři: /home/dan/Arduino/hardware/espressif/esp32/libraries/Ethernet
Použití knihovny ESPmDNS ve verzi 2.0.0 v adresáři: /home/dan/Arduino/hardware/espressif/esp32/libraries/ESPmDNS
Použití knihovny ArduinoOTA ve verzi 2.0.0 v adresáři: /home/dan/Arduino/hardware/espressif/esp32/libraries/ArduinoOTA
Použití knihovny Update ve verzi 2.0.0 v adresáři: /home/dan/Arduino/hardware/espressif/esp32/libraries/Update
Použití knihovny AsyncTCP ve verzi 1.1.1 v adresáři: /home/dan/Arduino/libraries/AsyncTCP
Použití knihovny ESPAsyncWebServer ve verzi 1.2.3 v adresáři: /home/dan/Arduino/libraries/ESPAsyncWebServer
Použití knihovny FS ve verzi 2.0.0 v adresáři: /home/dan/Arduino/hardware/espressif/esp32/libraries/FS
Použití knihovny AsyncElegantOTA ve verzi 2.2.5 v adresáři: /home/dan/Arduino/libraries/AsyncElegantOTA
Použití knihovny PubSubClient ve verzi 2.8 v adresáři: /home/dan/Arduino/libraries/PubSubClient
Použití knihovny Wire ve verzi 2.0.0 v adresáři: /home/dan/Arduino/hardware/espressif/esp32/libraries/Wire
Použití knihovny Adafruit_Unified_Sensor ve verzi 1.1.2 v adresáři: /home/dan/Arduino/libraries/Adafruit_Unified_Sensor
Použití knihovny Adafruit_BMP280_Library ve verzi 2.5.0 v adresáři: /home/dan/Arduino/libraries/Adafruit_BMP280_Library
Použití knihovny Adafruit_BusIO ve verzi 1.9.8 v adresáři: /home/dan/Arduino/libraries/Adafruit_BusIO
Použití knihovny SPI ve verzi 2.0.0 v adresáři: /home/dan/Arduino/hardware/espressif/esp32/libraries/SPI
Použití knihovny Adafruit_HTU21DF_Library ve verzi 1.0.4 v adresáři: /home/dan/Arduino/libraries/Adafruit_HTU21DF_Library
Použití knihovny SD_MMC ve verzi 2.0.0 v adresáři: /home/dan/Arduino/hardware/espressif/esp32/libraries/SD_MMC
Použití knihovny OneWire ve verzi 2.3.6 v adresáři: /home/dan/Arduino/libraries/OneWire
Použití knihovny DallasTemperature ve verzi 3.9.0 v adresáři: /home/dan/Arduino/libraries/DallasTemperature

*/
//-------------------------------------------------------------------------------------------------------
const char* REV = "20260629";
#define HWREVsw 8                   // software PCB version [7-8]
// #define AJAX                        // enable ajax web server
#define WINDY                      // upload to windy.com PWS (set station API key with 'K' menu command). TLS client is local + setInsecure() to save heap
// #define M_DNS                        // not work, but ArduinoOTA.setHostname() rewrite hostname
#define OTAWEB                      // enable upload firmware via web
#define TRXNET                      // P2P telemetry over local LAN (TrxNet lib): device name WX.<NET_ID hex>, NET_ID in EEPROM[1], 0=off
#define DS18B20                     // external 1wire Temperature sensor
#define BMP280                      // pressure I2C sensor
#define HTU21D                      // humidity I2C sensor
// #define SHT21                       // humidity I2C sensor
// #define SHT                         // general SHT sensors I2C sensor https://github.com/Sensirion/arduino-sht/blob/master/examples/multiple-sht-sensors/multiple-sht-sensors.ino
// #define RF69_EXTERNAL_SENSOR        // RX temp and humidity radio sensor RF69
#define ETHERNET                    // Enable ESP32 ethernet (DHCP IPv4)
#define ETH_ADDR 0
#define ETH_TYPE ETH_PHY_LAN8720
#if HWREVsw==8
  #define ETH_POWER 0                // #define ETH_PHY_POWER 0 ./Arduino/hardware/espressif/esp32/variants/esp32-poe/pins_arduino.h
#endif
#if HWREVsw==7
  #define ETH_POWER 12                // mosfet on VDDIO
#endif
#define ETH_MDC 23                  // MDC pin17
#define ETH_MDIO 18                 // MDIO pin16
#define ETH_CLK ETH_CLOCK_GPIO17_OUT    // CLKIN pin5 | settings for ESP32 GATEWAY rev f-g
String MACString;
char MACchar[18];
// #define ETH_CLK ETH_CLOCK_GPIO0_OUT    // settings for ESP32 GATEWAY rev c and older
// ETH.begin(ETH_ADDR, ETH_POWER, ETH_MDC, ETH_MDIO, ETH_TYPE, ETH_CLK);
// #define WIFI                     // Enable ESP32 WIFI (DHCP IPv4) - NOT TESTED
const char* ssid     = "";
const char* password = "";
const float FunelDiaInCM = 10.0; // cm funnel diameter
unsigned char HWREVpcb = 0;          // PCB version must be compatible with HWREVsw
//-------------------------------------------------------------------------------------------------------
// unsigned long TimerTemp;

// interrupts
#include "esp_attr.h"

// values
const int keyNumber = 1;
char key[100];
String YOUR_CALL = "";
/*
1mm rain = 15,7cm^2/10 = 1,57ml     <- by rain funnel radius
10ml = 11,5 pulses = 0,87ml/pulse   <- constanta tilting measuring cup
*/
// float mmInPulse = 0.87/(3.14*(FunelDiaInCM/2)*(FunelDiaInCM/2)/10); // calculate rain mm, in one pulse
// float mmInPulse = 0.2 ; // callibration rain 17,7-20,2 mm with 95 pulse
float mmInPulse = 0; // 0.65 ; // measure 3.8mm, reference 12.2mm

long MeasureTimer[2]={2800000,300000};   //  millis,timer (5 min)
long RainTimer[2]={0,5000};   //  <---------------- rain timing
int RainCount;
String RainCountDayOfMonth;
bool RainStatus;
int WindDir = 0;
int WindDirShift = 0;
float RainTodayMM = 0;
float WindSpeedAvgMPS = 0;
float WindSpeedMaxPeriodMPS = 0;

float PressureHPA = 0;
float TemperatureCelsius = 0;
float HumidityRelPercent = 0;
float DewPointCelsius = 0;

  float PressureHPaBMP280 = 0;
  float TemperatureCelsiusBMP280 = 0;
  float HumidityRelPercentHTU21D = 0;
  float DewPointCelsiusHTU21D = 0;
  float TemperatureCelsiusDS18B20 = 0;

volatile long RpmTimer[2]={0,3000};
volatile long RpmPulse = 987654321;
volatile long PeriodMinRpmPulse = 987654321;
String WindSpeedMaxPeriodUTC;
long MinRpmPulse;
String MinRpmPulseTimestamp;
// unsigned int RpmSpeed = 0;
volatile unsigned long RpmAverage[2]={0,0};  // counter,sum time
volatile bool RpmInterrupt = false;
volatile bool GustEvent = false;    // ISR flagged a new period-max (gust); loop timestamps + persists it
volatile long RollBucketMin = 987654321;   // shortest pulse since WindTask last folded it into a bucket
// All RPM state above is accumulated directly inside the IRAM-safe RPMcount() ISR and shared with
// loop() (core 1) + WindTask (core 0). rpmMux serialises access; use *_ISR variants inside the ISR.
portMUX_TYPE rpmMux = portMUX_INITIALIZER_UNLOCKED;
// Rolling "last 5 min" wind max for the dashboard, kept by WindTask in 30s buckets. Deliberately
// SEPARATE from WindSpeedMaxPeriodMPS (the publish-period max sent to MQTT/Windy/APRS), so the web
// shows a true trailing-5-min peak independent of the 5-min publish reset.
float WindRollMaxMps = 0;
String WindRollMaxUtc = "";
int InterruptDepth = 0;             // nesting counter for Interrupts(false/true)
float TempCal=0;

int SpeedAlertLimit_ms = 0;
int SpeedAlert_ms = 3000;
// bool NeedSpeedAlert_ms = false;
long AlertTimer[2]={0,60000};
//  |alert...........|alert........... everry max 1 minutes and with publish max value in period

// 73 seconds WDT (WatchDogTimer)
#include <esp_task_wdt.h>
#define WDT_TIMEOUT 73
long WdtTimer=0;

// Software watchdog - recovers from failures the HW task-WDT cannot catch
// (network stack death / socket- or heap-exhaustion while loop() keeps running and feeding the WDT).
#define CONN_LOST_REBOOT_MS 900000UL   // 15 min without ETH connectivity -> restart (MQTT may be absent on an island LAN)
#define HEAP_MIN_FREE 20000            // bytes; if free heap drops below this -> restart
unsigned long ConnOkTimer=0;           // millis() of last healthy ETH state

byte InputByte[21];
// #define Ser2net                  // Serial to ip proxy - DISABLE if board revision 0.3 or lower
// #define EnableOTA                // Enable flashing ESP32 Over The Air (port 3232 IDE/espota - unused, disabled to save ~33 KB flash; web OTA on :82 stays)
// int NumberOfEncoderOutputs = 8;  // 2-16
int EnableSerialDebug     = 0;
long FreneticModeTimer ;
#define HTTP_SERVER_PORT  80     // Web server port

const int SERIAL_BAUDRATE = 115200; // serial debug baudrate
int SERIAL1_BAUDRATE; // serial1 to IP baudrate
int incomingByte = 0;   // for incoming serial data

int i = 0;
#include <WiFi.h>
// mDNS
#if defined(M_DNS) && defined(ETHERNET)
  #include <ESPmDNS.h>
#endif
#include "EEPROM.h"
#define EEPROM_SIZE 470   /* up to 512
0|Byte    1|128
1|Char    1|A
2|UChar   1|255
3|Short   2|-32768
5|UShort  2|65535
7|Int     4|-2147483648
11|Uint    4|4294967295
15|Long    4|-2147483648
19|Ulong   4|4294967295
23|Long64  8|0x00FFFF8000FF4180
31|Ulong64 8|0x00FFFF8000FF4180
39|Float   4|1234.1234
43|Double  8|123456789.12345679
51|Bool    1|1

0    - (free, was: listen source)
1    - TrxNet NET_ID (uint8, device id only; enable is byte 35)
2-3  - TempCal Short
4    - HWREVpcb UChar
5    - mmInPulse Short
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
void loop() {
  webserver.handleClient();
  Mqtt();
  CLI();
  Telnet();
  Watchdog();

  #if defined(TRXNET)
  if(TrxNetEnable){
    if(trxStarted==false && eth_connected==true){   // start once ETH is up and TrxNet enabled
      snprintf(trxDeviceName, sizeof(trxDeviceName), "WX.%02x", NET_ID);
      trxNet.setPort(trxPort);             // must be called before begin()
      trxNet.onPeerAdded(TrxNetOnPeerAdded);
      trxNet.begin(trxDeviceName);
      trxStarted=true;
    }
    if(trxStarted==true){
      trxNet.loop();
      // Drain ONE queued greet per iteration - keeps the CON pending queue bounded to
      // one peer's snapshot (7 topics) at a time (see TrxNet README "greet new peer").
      if(trxGreetCount>0){
        trxGreetCount--;
        TrxNetPublish(trxGreet[trxGreetCount]);
      }
    }
  }
  #endif

  // check_radio();

  // blank loop 80us
  // SerialToIp();
  // if(millis()-TimerTemp > 60000){
  //   String StringUtc1 = UtcTime(1);
  //   // MqttPubString("tmp/utc", StringUtc1, false);
  //   sensors.requestTemperatures();
  //   float temperatureC = sensors.getTempCByIndex(0);
  //   MqttPubString("tmp/c", StringUtc1+" "+String(temperatureC), false);
  //   TimerTemp=millis();
  // }

  /*
  Scanning...
  I2C device found at address 0x40 - HTU21D - Humidity + Temp sensor
  I2C device found at address 0x76 - BMP280 - Pressure sensor
  */
  #if defined(EnableOTA)
   ArduinoOTA.handle();
  #endif

  #if defined(OTAWEB)
   // OTAserver.on("/printIp", HTTP_GET, [](AsyncWebServerRequest *request){
   //     request->send(200, "text/plain", "ok");
   //     Serial.println(request->client()->remoteIP());
   // });
   AsyncElegantOTA_IPR.loop();
  #endif
}
// SUBROUTINES -------------------------------------------------------------------------------------------------------

void IRAM_ATTR RPMcount(){    // must be before attachInterrupt ;)
  // IRAM-safe ISR: reads the pin straight from the GPIO register (digitalRead is not guaranteed to
  // stay in IRAM, which would crash if the ISR fired during a flash write) and does ALL min/max/avg
  // accumulation here under rpmMux. Because every pulse is counted at the instant it arrives, gusts
  // are captured even while loop() is busy (web/MQTT/TLS) and even during EEPROM commits - we no
  // longer detach the interrupt for those. Only integer math + millis() (both IRAM-safe) run here;
  // the timestamp + EEPROM persistence of the lifetime max stay in loop()/Watchdog (see GustEvent).
  // RpmPin=39 lives in the GPIO 32-39 bank, read via GPIO_IN1_REG bit (pin-32).
  if(((REG_READ(GPIO_IN1_REG) >> (RpmPin - 32)) & 0x1) != 0) return;   // pin not low -> ignore (FALLING confirm)

  portENTER_CRITICAL_ISR(&rpmMux);
  unsigned long now = millis();
  long pulse = (long)(now - RpmTimer[0]);
  RpmTimer[0] = now;
  if(pulse < 10){                       // <10ms => >300km/h => electrical noise, treat as "no reading"
    RpmPulse = 987654321;
  }else{
    RpmPulse = pulse;
    if(pulse < PeriodMinRpmPulse){      // shorter period = faster wind = new period max (gust)
      PeriodMinRpmPulse = pulse;
      GustEvent = true;                 // loop() will timestamp it and persist a new lifetime max
    }
    if(pulse < RollBucketMin){          // feed the rolling 5-min window (WindTask buckets this)
      RollBucketMin = pulse;
    }
    if(pulse < RpmTimer[1]){            // only pulses < 3s count into the running average (ignore calm)
      RpmAverage[1] += pulse;
      RpmAverage[0]++;
    }
  }
  RpmInterrupt = true;
  portEXIT_CRITICAL_ISR(&rpmMux);
}
//-------------------------------------------------------------------------------------------------------
void Interrupts(boolean ON){
  // nesting safe - inner Interrupts(true) must not re-enable prematurely
  if(ON==true){
    if(InterruptDepth>0){
      InterruptDepth--;
    }
    if(InterruptDepth==0){
      attachInterrupt(RpmPin, RPMcount, FALLING);
    }
    // attachInterrupt(digitalPinToInterrupt(RpmPin), RPMcount, FALLING);
    // attachInterrupt(digitalPinToInterrupt(RpmPin), RPMcount, RISING);
  }else{
    if(InterruptDepth==0){
      detachInterrupt(digitalPinToInterrupt(RpmPin));
    }
    InterruptDepth++;
  }
}
//-------------------------------------------------------------------------------------------------------
// The RPM ISR is now fully IRAM-safe (register read + integer math, no flash-resident calls), so it
// may keep firing while the flash is being written - no need to detach it around the commit anymore.
void EEPROMcommit(){ EEPROM.commit(); }

// Persist today's rain counter to EEPROM so a reboot (recovery restart / power loss)
// does not lose the daily rain total. Writes only when the value changed (EEPROM wear).
void RainCountStore(){
  int d = RainCountDayOfMonth.toInt();   // "26"->26 ; "n/a"->0
  if(d>=1 && d<=31){
    if(EEPROM.readByte(368)!=(byte)d || EEPROM.readInt(369)!=RainCount){
      EEPROM.writeByte(368, (byte)d);
      EEPROM.writeInt(369, RainCount);
      EEPROMcommit();
    }
  }
}

// Restore today's rain counter from EEPROM at boot. The day-change logic in GetValue()
// (UtcTime(2)!=RainCountDayOfMonth) then keeps it for the same day or zeroes it across midnight.
void RainCountRestore(){
  byte d = EEPROM.readByte(368);
  if(d>=1 && d<=31){
    int c = EEPROM.readInt(369);
    if(c<0 || c>100000){ c=0; }   // guard against unset/corrupt value
    RainCount = c;
    RainCountDayOfMonth = (d<10?"0":"") + String(d);   // zero-padded to match UtcTime(2) "%d"
  }else{
    RainCount = 0;
    RainCountDayOfMonth = UtcTime(2);
  }
}
//-------------------------------------------------------------------------------------------------------
void Watchdog(){

  // RPM - the min/max/avg accumulation now happens inside the IRAM-safe RPMcount() ISR (so no pulse
  // is lost while loop() is busy). Here we only react to a gust flagged by the ISR: stamp the time of
  // the new period max and, if it also beats the lifetime record, persist it to EEPROM. The ISR can
  // keep firing during EEPROMcommit() because it is fully IRAM-safe, so we no longer detach it.
  if(GustEvent==true){
    portENTER_CRITICAL(&rpmMux);
    GustEvent = false;
    long periodMin = PeriodMinRpmPulse;   // shortest period seen this window = the gust
    portEXIT_CRITICAL(&rpmMux);

    WindSpeedMaxPeriodUTC = UtcTime(1);
    if(periodMin < MinRpmPulse && needEEPROMcommit==false){
      MinRpmPulseTimestamp = WindSpeedMaxPeriodUTC;
      MinRpmPulse = periodMin;
      EEPROM.writeLong(169, MinRpmPulse);
      EEPROM.writeString(173, MinRpmPulseTimestamp);
      needEEPROMcommit = true;
    }
    if(needEEPROMcommit==true){
      needEEPROMcommit = false;
      EEPROMcommit();
      MqttPubString("WindSpeedMax-mps", String(PulseToMetterBySecond(MinRpmPulse)), true);
      MqttPubString("WindSpeedMax-utc", String(MinRpmPulseTimestamp), true);
    }
  }


  // WDT
  if(millis()-WdtTimer > 60000){
    esp_task_wdt_reset();
    WdtTimer=millis();
    if(EnableSerialDebug>0){
      Prn(3, 0,"WDT reset ");
      Prn(3, 1, UtcTime(1));
    }
  }

  // Software watchdog - recover from failures the HW task-WDT can't catch.
  // The HW WDT only detects a frozen loop()/CPU. The real long-term failure mode is the
  // network stack dying (socket/heap exhaustion) while loop() keeps running and feeding the WDT.
  // Here we restart if ETH connectivity has been lost too long, or free heap is critically low.
  // (MQTT loss alone does NOT trigger a restart - the station must keep running on an island LAN.)
  {
    static unsigned long ConnLastCheck=0;
    if(millis()-ConnLastCheck > 5000){   // check every 5s
      ConnLastCheck=millis();
      if(eth_connected==true){
        ConnOkTimer=millis();   // healthy - ETH link/IP is what we watch (MQTT may be intentionally absent on an island LAN)
      }
      bool recoveryReboot=false;
      if(ConnOkTimer>0 && millis()-ConnOkTimer > CONN_LOST_REBOOT_MS){
        Prn(3, 1,"** Software watchdog: ETH connectivity lost too long - restart **");
        recoveryReboot=true;
      }
      if(ESP.getFreeHeap() < HEAP_MIN_FREE){
        Prn(3, 1,"** Software watchdog: free heap critically low ("+String(ESP.getFreeHeap())+" B) - restart **");
        recoveryReboot=true;
      }
      if(recoveryReboot==true){
        RainCountStore();   // persist today's rain so the recovery reboot does not lose it
        delay(200);
        ESP.restart();
      }
    }
  }
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

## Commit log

2021-01-23 pressure by altitude
2022-10-01 20221001|fix save shift|modify CLI
    [wx.ino]
2023-08-25 add dew point, fix shift register, recalibrate rain
    [wx.ino]
2023-08-25 add PCB rev | add 3D print model
    [1.stl, 10.stl, 11.stl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]
2023-08-26 update 3D model part #11
    [11.stl, BLACK.3mf, wx-station.scad]
2023-08-27 fix temperature shift telnet input
    [wx.ino]
2023-09-03 fix 3d print part nr 1
    [1.stl, WHITE.3mf, wx-station.scad]
2023-09-03 add 3D print sunshield for external termistor
    [sun-shield-base-35mm.stl, sun-shield-base-42mm.stl, sun-shield-bot.3mf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]
2024-02-11 fix rain count + some small changes
    [wx.ino]
2026-06-26 ai bugfix
    [wx-station.scad]
2026-06-26 fix send data to aprs
    [wx.ino]
2026-06-26 redesign web ui
    [partitions.csv]
2026-06-26 change filesystem to old/previous size
    [partitions.csv]

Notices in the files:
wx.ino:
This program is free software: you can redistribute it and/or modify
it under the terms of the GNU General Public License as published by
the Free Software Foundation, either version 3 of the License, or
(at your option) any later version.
